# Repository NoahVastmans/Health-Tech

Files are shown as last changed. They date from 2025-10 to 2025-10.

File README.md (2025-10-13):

# 🎾 SmartServe Ball — Intelligent Motion Guidance and Apex Detection

## 📘 Project Overview

The **SmartServe Ball** project combines embedded sensing, wireless communication, and data analysis to accurately detect and predict the **apex** of a tennis ball’s trajectory during a throw or serve.

Using a **Seeed XIAO BLE Sense** microcontroller with a **6-axis IMU (LSM6DS3)**, the system identifies:
- The **start of free fall**
- The **apex (highest point)** of the throw
- The **catch or impact moment**
- And transmits timing data via **Bluetooth Low Energy (BLE)**

The goal is to provide **real-time motion insight** for sports technology, validation through **video tracking**, and a foundation for further embedded motion analytics.

---

## 📁 Repository Structure

### 🧠 `Arduino Scripts/`
Contains all embedded code for the SmartServe Ball, including:
- **Apex detection**, **free-fall**, and **BLE telemetry algorithms**
- Modified **`LSM6DS3.cpp`** file required for stable IMU communication  
  *(instructions are detailed in the script-specific README inside this folder)*

Each Arduino script is fully documented in-code.

---

### ⚡ `Electrical Circuit/`
Includes the electrical design and assembly details:
- **KiCad project files** for the wiring and sensor connections  
- **Photos** of the final sensor assembly

> 💡 The PCB was **not fully designed** in CAD — instead, an **adaptable PCB prototyping board** was used.  
> This allowed greater flexibility for multi-layer connections and double-sided component placement.

---

### 🧱 `Prototype Sensor Case/`
3D design files for the **protective casing** used to house the electronics inside a **tennis ball**.  
The case ensures durability while maintaining balance and minimal aerodynamic impact.

---

### 🎥 `Video Tracking/`
Contains:
- The **validation videos** used to visually confirm the apex timing  
- **Video tracking scripts** for extracting apex frames and timestamps  
- A **comparison file** matching BLE-detected and predicted times to the visual apex times

This folder provides the link between **experimental results** and **sensor-based detection accuracy**.

---

### 📹 `Explanation Video/`
A short **demonstration video** summarizing the SmartServe Ball project — explaining the concept and system design in a clear visual format.

---

### 🖥️ `Presentation/`
Contains the **final project presentation slides**, summarizing:
- Motivation and goals  
- Technical design (hardware + software)  
- Validation results and future improvements  

---

### 📄 `Scientific Paper/`
Includes a **concise research-style paper** presenting:
- The experimental setup  
- Measured results  
- Comparison between prediction and detection  
- Relevant literature and references  

---

### 🕰️ `Legacy/`
Contains earlier versions of scripts and design assets intended for future development.  
A separate README inside this folder explains each file’s purpose and how to build upon it.

---

## 🧩 Summary

| Component | Description |
|---|---|
| **Embedded Code** | Apex detection, prediction, BLE telemetry |
| **Electronics** | IMU wiring and modular circuit design |
| **Mechanical Design** | 3D CAD for protective case |
| **Validation** | Video-based apex verification |
| **Demonstration** | Project explanation video |
| **Documentation** | Presentation slides and scientific paper |
| **Legacy Work** | Early-stage materials for continuation |

---

## 🔬 Purpose

The SmartServe Ball demonstrates how **low-power embedded sensing** and **motion algorithms** can yield **accurate trajectory analytics** for sports applications.  
It combines open hardware, transparent validation, and modular design to serve as a **research and development platform** for motion-based performance tracking.

---

## 🧾 License

This repository is open for **educational and research use**.  
Please credit the **SmartServe Ball Project** when reusing or modifying any material.

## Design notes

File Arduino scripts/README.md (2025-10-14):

# 🎾 SmartServe Ball — Apex Detection, Apex Estimation & BLE Telemetry

## 📖 Overview

**SmartServe Ball** is an embedded system that detects and measures the motion of a thrown object using a **6-axis IMU (LSM6DS3)** and **Bluetooth Low Energy (BLE)**.

It automatically detects:
- **Free fall start** and **catch impact**
- The **apex (highest point)** of flight
- **Predicted vs. actual apex times**
- And emits a **buzzer signal** for video synchronization or real-time feedback.

Flight metrics are transmitted via BLE to a connected device (e.g., smartphone, PC, or logging app).

---

## 🧭 Setup Prerequisites

Before you begin, make sure your development environment is correctly configured for the **Seeed XIAO BLE Sense**.

1. 📘 **Read the official Seeed Studio setup guide:**  
   👉 [https://wiki.seeedstudio.com/XIAO_BLE/](https://wiki.seeedstudio.com/XIAO_BLE/)  
   This page explains how to properly set up the board, drivers, and Arduino environment.

2. ⚙️ **Install the correct board package:**  
   In the Arduino IDE, go to  
   `Tools → Board → Board Manager`  
   and install:  
   **“Seeed nRF52 mbed-enabled Boards”**  
   **Do not install the non-mbed version**, as it may cause upload and sensor initialization issues.

Once the board package is installed, select:  
`Tools → Board → Seeed XIAO BLE Sense`

---

## ⚙️ System Features

| Feature | Description |
|---|---|
| **Free-fall detection** | Detects when acceleration drops below ~0.1 g |
| **Apex detection** | Zero-crossing of filtered vertical velocity |
| **Apex prediction** | Calculates time to apex based on release velocity |
| **Catch detection** | Detects when acceleration rises after flight |
| **BLE transmission** | Sends flight metrics as a comma-separated string |
| **Buzzer feedback** | Beeps at apex for video synchronization |
| **Continuous mode** | Supports multiple throws in sequence |

---

## 🧩 Hardware Requirements

- **Seeed XIAO BLE Sense** or compatible BLE-enabled Arduino board  
- **LSM6DS3 IMU** (integrated or connected via I²C)
- **Buzzer** connected to **pin 5**
- Optional: mobile app or BLE logger to receive flight data

---

## 🔧 Software Requirements

- **Arduino IDE 2.x**  
- **Libraries:**
  - `LSM6DS3` (Seeed version)
  - `ArduinoBLE`
  - `Wire`

---

## ⚠️ Important — LSM6DS3.cpp Modification

Before running this code, you **must replace** the `LSM6DS3.cpp` file in your installed library folder with the **modified version** included in this project.

This modified file ensures **stable and faster sensor reads** compatible with the SmartServe Ball’s timing requirements.

### 🔹 Steps to Replace the File:

1. Locate your LSM6DS3 library folder:
   - **Windows:**  
     `Documents/Arduino/libraries/Seeed_Arduino_LSM6DS3/`
   - **macOS/Linux:**  
     `~/Documents/Arduino/libraries/Seeed_Arduino_LSM6DS3/`

2. Find and replace the file:
   - Replace the original `LSM6DS3.cpp` with the version found in this SmartServe Ball project folder.

3. Restart the Arduino IDE.

---

## 🧠 Algorithm Summary

### 1. **Sampling**
- The IMU is sampled at **52 Hz** (`fs = 52.0`).
- Each cycle reads acceleration and computes its norm.

### 2. **Filtering**
- **Low-pass filter** smooths acceleration (`fc_acc = 5 Hz`).
- **High-pass filter** integrates to get drift-free velocity (`fc_vel = 50 Hz`).

### 3. **Free-Fall Detection**
- Triggered when acceleration norm < `FREEFALL_THRESH` (≈ –7 m/s²) for at least `FREEFALL_MIN` s.

### 4. **Apex Prediction**
- Using initial velocity (`v₀`), predicts the time to apex:  
  `t_pred = v₀ / g`

### 5. **Apex Detection**
- Detected when filtered velocity crosses zero (positive → negative).
- A buzzer beep is scheduled with a delay compensation of `filter_delay` s.

### 6. **Catch Detection**
- Ends flight when acceleration norm > `CATCH_THRESH` (≈ 1 m/s²).

### 7. **BLE Transmission**
- Sends a string formatted as:  
  `t_pred_apex, apex_since_freefall, freefall_duration`

Example: `0.735, 0.740, 1.488`

---

## 📡 BLE Data Format

| Field | Description | Units |
|---|---|---|
| `t_pred_apex` | Predicted time from release to apex | s |
| `apex_since_freefall` | Actual measured apex time (since free-fall start) | s |
| `freefall_duration` | Total flight time | s |

BLE UUIDs:
- **Service:** `180A`  
- **Characteristic:** `2A57`

---

## 🔔 Buzzer Behavior

| Event | Action |
|---|---|
| Free fall start | Short tone (500 Hz, 100 ms) |
| Apex | 1 kHz tone, delayed by `filter_delay` |
| Catch | No tone; BLE data sent |

---

## ⚙️ Tuning Parameters

| Parameter | Description | Default |
|---|---|---|
| `fs` | Sampling frequency | 52 Hz |
| `fc_acc` | Low-pass cutoff for acceleration | 5 Hz |
| `fc_vel` | High-pass cutoff for velocity | 50 Hz |
| `FREEFALL_THRESH` | Acceleration threshold (≈ 0.1 g) | –7.0 m/s² |
| `FREEFALL_MIN` | Minimum time below threshold | 0.04 s |
| `CATCH_THRESH` | Catch detection threshold | 1.0 m/s² |
| `filter_delay` | Apex delay compensation | 0.12 s |
| `buzzerDuration` | Tone duration | 500 ms |

---

## 📈 Example BLE Output

```
0.733, 0.751, 1.486
0.812, 0.798, 1.612
0.705, 0.739, 1.423
```

Each line corresponds to one complete throw:
1. Predicted apex time  
2. Detected apex time since free-fall start  
3. Flight duration (end – start)

---

## 🚀 Usage Steps

1. Replace the **LSM6DS3.cpp** file as described above.  
2. Open the `Apex_detection_and_prediction.ino` sketch in Arduino IDE.  
3. Select your board (e.g., Seeed XIAO BLE Sense) and COM port.  
4. Upload the sketch.  
5. Open a BLE terminal or app (e.g., **nRF Connect**, **Serial Bluetooth Terminal**).  
6. Start throwing the ball — observe BLE data and buzzer signals.

---

## 🧰 Future Extensions

- Include **gyro-based orientation** for 3D trajectory tracking.  
- Add **drag correction** to apex prediction.  
- Store data on the **internal flash memory** of the Seeed board, allowing for **delayed Bluetooth transmission** — removing the need for a constant connection to retrieve data.
---

## 📄 License

This project is open for educational and research use.  
Please credit the **Smart Ball Project** when redistributing or modifying.

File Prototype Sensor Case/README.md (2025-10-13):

# 🧱 Prototype Sensor Case
3D design files for the protective casing used to house the electronics inside a tennis ball.
The case ensures durability while maintaining balance.

## 📘 Overview

This folder contains all **cad design resources** for the SmartServe Ball project.  
The 3D printed case is design to work with the first version of the SmartServe Ball as described in **electrical design resources**.

---

## 🧩 Contents

| Item | Description |
|---|---|
| `sensor case_prototype.step` | sensor case concept for SmartServe Ball in .step format |
| `sensor case_prototype.sldprt` | sensor case concept for SmartServe Ball in .sldprt format |
| `assembly` | Image of the final sensor assembly for a tennis ball integration in a "Exploded" view |

---

## 🧠 Design Notes

- The sensor case serves purpose as a **proof of concept** for rapid prototyping.
- It is designed to be manufactured in a **3D printing machine** under the material of **Polyurethane (PTU)**.
  -  Flexibility and Elasticity
  -  Tensile Strength
  -  Impact Resistance
  -  Tear Resistance
- Tailormade designed to the specific dimensions of the SmartServe Ball.
- Design pivots from the manufacturing process of a tennis ball.
- The **sensor case itself was not tested** by any FEA system or physical examination.

---

## 🔌 Implementation Overview

The assembly image illustrates: 
- **Tennis Ball Outer Felt layer** 6cm diameter  
- **Tennis Ball Inner Rubber Core** 3mm thick
- **Sensor case prototype**
- **SmartServe Ball sensor system**
    
---

## 🧰 Tools

- **Any CAD design software** (for viewing and editing files)  
- **SolidWorks** (original CAD designed software use)

Consideration when opening the part:
1. Model uses external reference of the components of the SmartServe Ball.  
2. Therefore, to use in other systems.
  a. External references may need to be broken.
  b. Adjust contour sketches to match the components' dimensions.  

---

## 🧾 License

These files are shared for **educational and research purposes** under the SmartServe Ball project.  
Please credit the **SmartServe Ball Team** when reusing or adapting the schematic or library components.

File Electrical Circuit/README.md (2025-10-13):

# ⚡ SmartServe Ball — Electrical Circuit

## 📘 Overview

This folder contains all **electrical design resources** for the SmartServe Ball project.  
The system connects a **Seeed XIAO BLE Sense** microcontroller to a **buzzer** and other peripheral components.

---

## 🧩 Contents

| Item | Description |
|---|---|
| `SmartServeBall.kicad_sch` | Main circuit schematic showing all connections between the XIAO BLE Sense, IMU, and buzzer |
| `SmartServeBall.kicad_pro` | KiCad project configuration file |
| `Seeeduino XIAO KICAD/` | KiCad symbol and footprint files for Seeed components (used in the schematic) |
| `Assembly Photos/` | Images of the final sensor assembly and adaptable PCB setup |

---

## 🧠 Design Notes

- Only the **schematic** was designed digitally in KiCad.  
- The **PCB itself was not routed** in KiCad or fabricated.

Instead, an **adaptable prototyping PCB** was used for greater flexibility:
- Components were mounted on **both sides** of the board.  
- Components were mounted on top of each other to save space.  
- This approach allowed **rapid iteration** and **easy modification** during testing and validation.

---

## 🔌 Connection Overview

The schematic illustrates: 
- **Power lines** (`3.3V` and `GND`) shared between all components  
- **Digital output pin (D5)** used to drive the **buzzer** for apex and event feedback

---

## 🧰 Tools

- **KiCad 7.x or later** (for viewing and editing schematic files)  
- **Seeeduino XIAO KICAD Library** (included in this folder)

To open the schematic correctly:
1. Ensure the `Seeeduino XIAO KICAD/` folder is in the same directory as the `.kicad_pro` file.  
2. Open `SmartServeBall.kicad_pro` in KiCad.  
3. Verify that component symbols and footprints load without errors.

---

## 🧱 Assembly Process

The assembly was performed in several structured steps to create a compact and robust sensor module:

1. **Top Layer Soldering:**  
   The first layer of components was soldered on the **upper side** of the adaptable PCB.  
   This included the **buzzer**, **resistor**, and **pin extensions** for the Seeed XIAO BLE Sense.

2. **Power Wiring:**  
   Next, the **power supply wires** were soldered to the corresponding **3.3V** and **GND** pins, ensuring solid electrical contact and mechanical stability.

3. **Base Layer Protection:**  
   After soldering the lower connections, a **thin layer of hot glue** was applied to the **bottom side** of the PCB to insulate and protect the solder joints.

4. **Battery Holder Placement:**  
   The **battery holder** was then positioned directly on top of the glued surface, forming the **second hardware layer** of the design.

5. **Final Power Connection:**  
   Finally, the **power wires** were soldered to the **battery holder terminals**, completing the electrical circuit and enabling portable operation.

This stacked-layer assembly provided an **efficient use of space** and **robust wiring**, allowing the electronics to fit neatly inside the SmartServe Ball’s protective enclosure.

---

## 📷 Assembly

The `Assembly_Photos/` folder shows:
- The **adaptable PCB layout**  
- The **component placement** on both board sides  

These images serve as a **reference for replication or redesign**.

---

## 🧾 License

These files are shared for **educational and research purposes** under the SmartServe Ball project.  
Please credit the **SmartServe Ball Team** when reusing or adapting the schematic or library components.

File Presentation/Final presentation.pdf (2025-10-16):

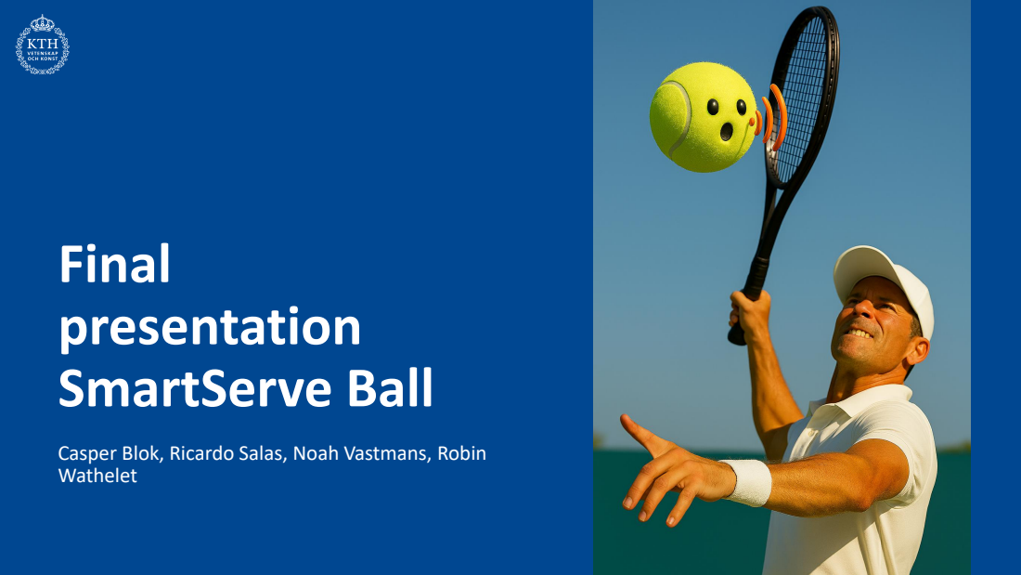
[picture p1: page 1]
Final presentation SmartServe Ball

Casper Blok, Ricardo Salas, Noah Vastmans, Robin
Wathelet

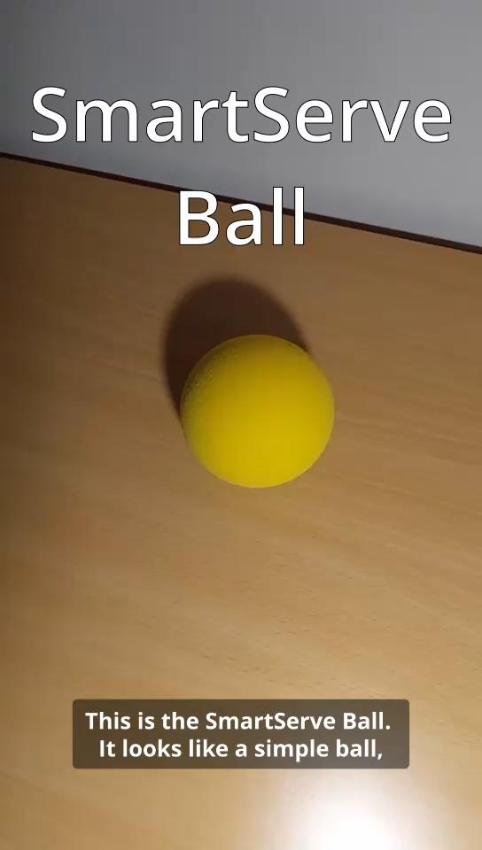
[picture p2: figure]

# Video

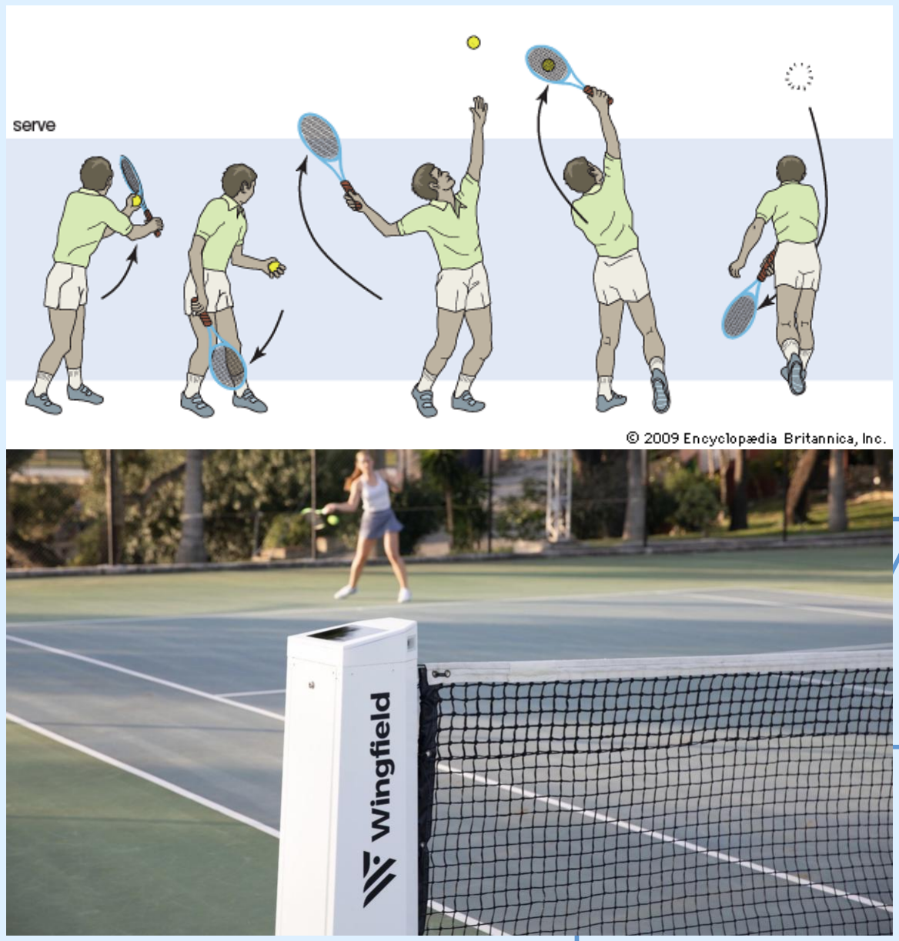
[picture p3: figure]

# Problem Statement

- Difficult evaluation of tennis serve timing
- Alternative solutions:
- Coach → unreliable
- Video analysis → expensive setup

# Technical design

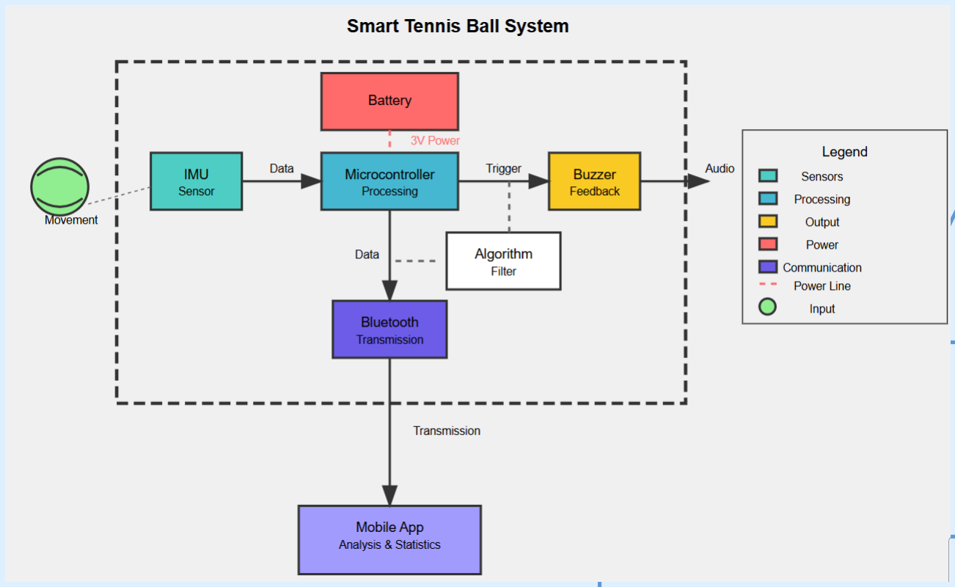
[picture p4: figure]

- Seeed Studio XIAO nRF52840 Sense board
- IMU
- Microcontroller
- Bluetooth module
- Integrated electrical circuit with buzzer and coin battery
- Training foam ball

# Technical design

- Velocity reconstruction from acceleration
- Freefall detection: flight time
- Apex detection → trigger acoustic feedback

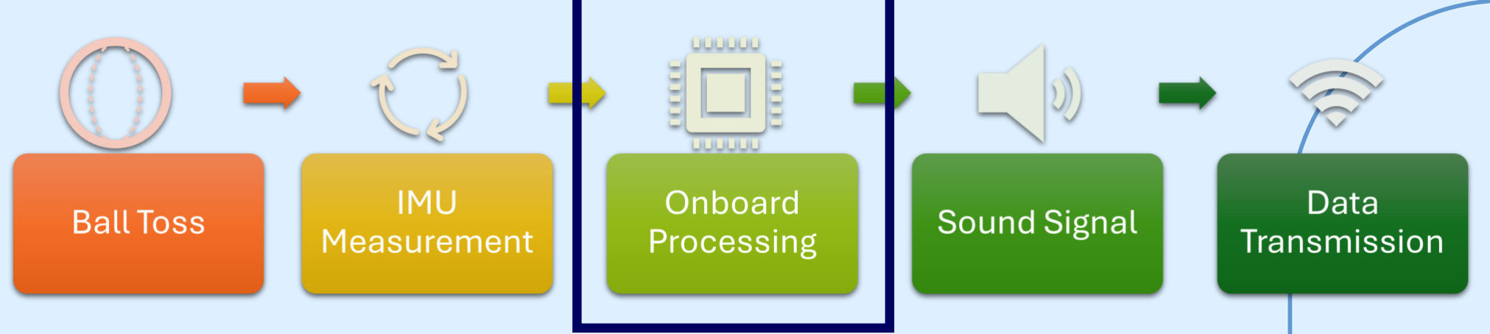
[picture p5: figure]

# User Interaction

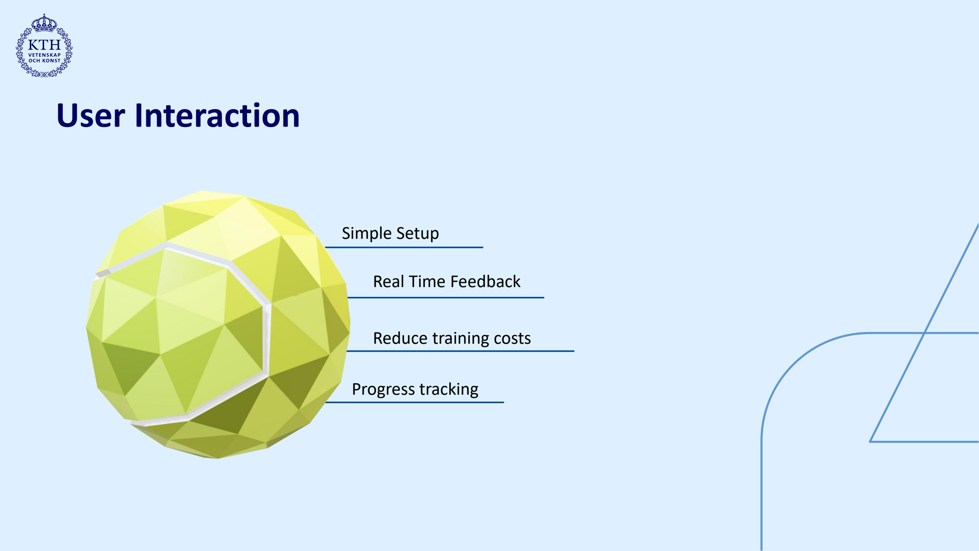
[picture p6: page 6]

Simple Setup

Real Time Feedback

Reduce training costs

Progress tracking

# Results

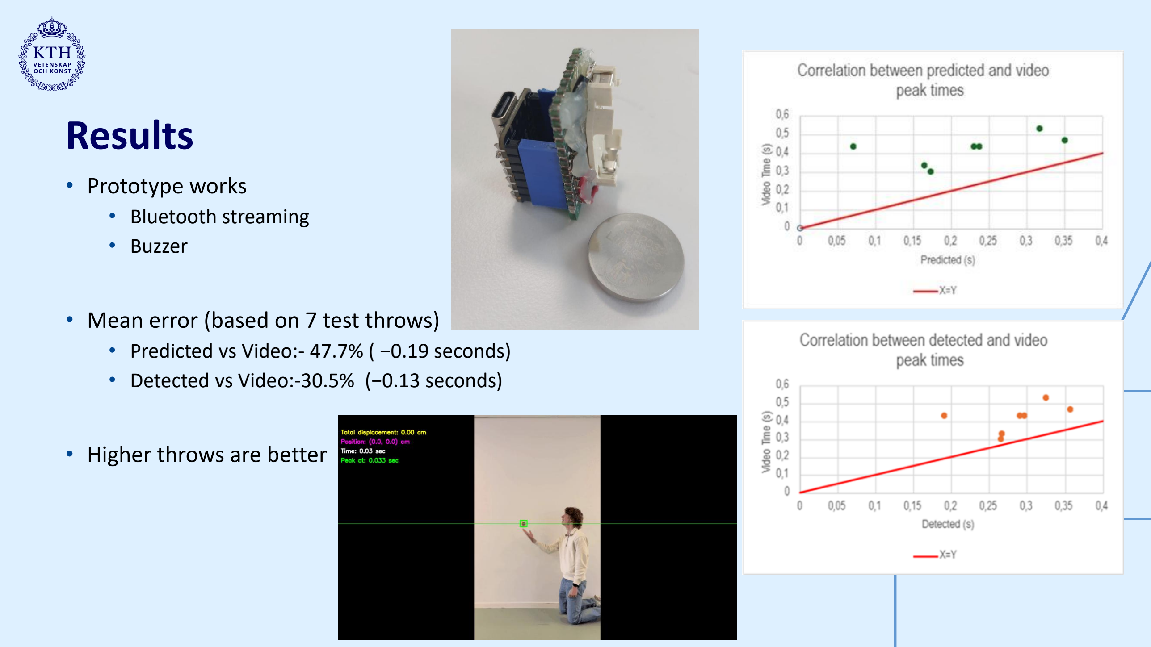
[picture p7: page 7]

- Prototype works
- Bluetooth streaming
- Buzzer
- Mean error (based on 7 test throws)
- Predicted vs Video:- 47.7% ( −0.19 seconds)
- Detected vs Video:-30.5% (−0.13 seconds)
- Higher throws are better

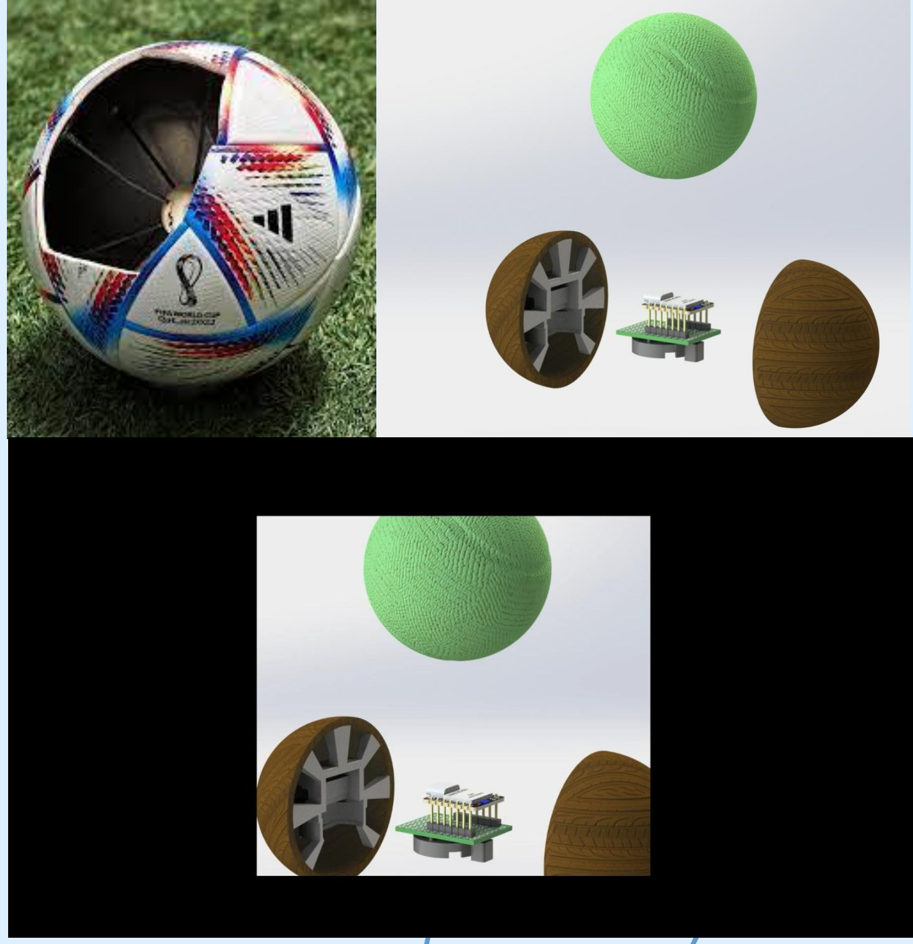
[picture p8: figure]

# What's next

- Integration into a real tennis ball
- Provide sufficient integrity
- Center of rotation
- Affect minimal initial properties
- Weight
- Balance
- Elasticity
- Improve accuracy
- Both detection and video validation
- Onboard data storage → delayed transmission
- App design for progress tracking

# Other Uses

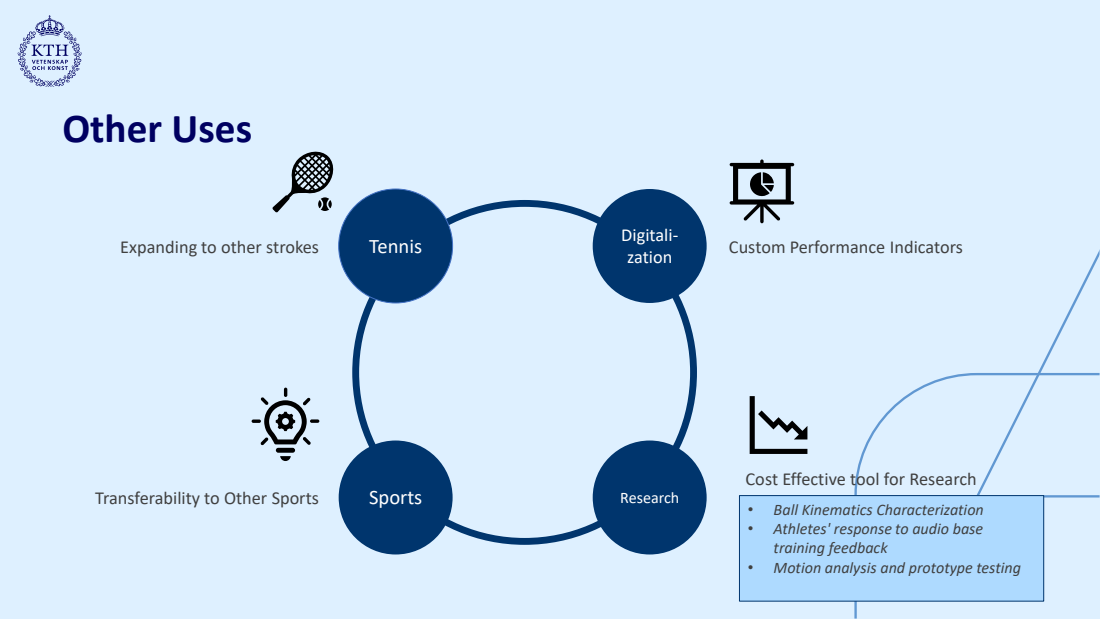
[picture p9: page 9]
Tennis; Digitali-; zation; Sports; Research

Expanding to other strokes

Custom Performance Indicators

Cost Effective tool for Research

Transferability to Other Sports

• Ball Kinematics Characterization
• Athletes' response to audio base
training feedback
• Motion analysis and prototype testing

# Project Methodology

Positive
- Weekly meetings
- Strong communication

Leasons learned
- More communication between members about their work
- Seeking help at an earlier stage when stuck

The group dynamic is centered around an open table discussion.
- Brainstorming
- Collectively discuss ideas
- Parallel work

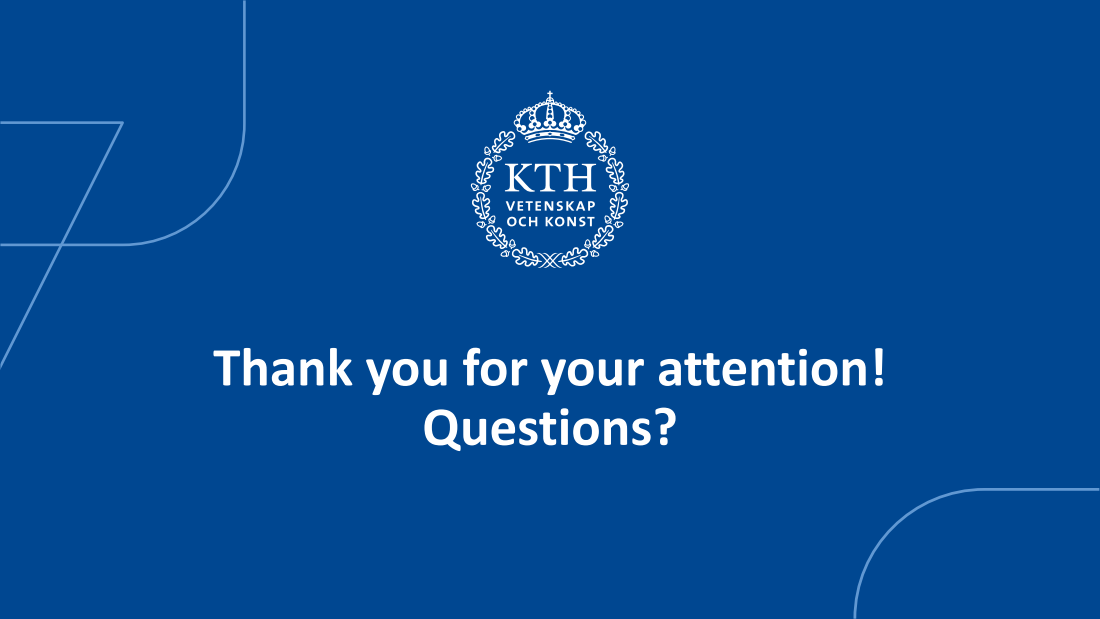
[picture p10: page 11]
Questions?

Thank you for your attention!

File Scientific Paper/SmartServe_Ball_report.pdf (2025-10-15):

CM 2024: Technology and Health, project course | October 15, 2025

## SmartServe: A Sensor-Embedded Tennis Ball for Real-Time Apex Detection and Feedback

Casper Blok, Ricardo Salas, Noah Vastmans, Robin Wathelet

Abstract

This project addresses the challenge of improving tennis serve technique by accurately detecting the apex of the ball toss. A critical aspect of the serve is timing the strike, as mistimed serves reduce performance consistency and are difficult for players to correct without precise feedback. To address this, we developed SmartServe, a prototype ball equipped with a Seeed nRF52840 board and custom firmware designed to detect and record the highest point of the toss. The system provides real-time audio cues to guide the player. The tests showed that SmartServe identified the apex with an average accuracy of −30% in repeated trials, demonstrating robust sensing and reliable data retrieval.

## Introduction

In tennis, one of the key factors that determines the outcome of a match is the ability to serve [1]. The quality of the serve is strongly influenced by the timing between the ball toss and impact [2]. However, amateur players often struggle to consistently recognize and time their swing [3, 4].
Current methods for improving serve timing rely heavily on subjective or indirect approaches. The most common method is coach feedback, which provides expert guidance but depends on the coach’s availability and observational accuracy. More advanced motion tracking systems, such as radar or camera-based sports analytics tools, can provide detailed measurements of ball speed and spin. Still, their high cost and operational complexity make them beyond the reach of most players [5, 6]. These systems have primarily been applied in scientific research contexts, requiring extensive data analysis [3, 4, 7], and are also used in elite tournaments, Hawk-Eye being the most widely adopted system [8]. Recent studies have explored more affordable setups, achieving promising results, but these require post-processing (i.e., AdaBoost algorithms to video track small objects [9]).
These approaches highlight the need for a more direct, in-situ solution capable of measuring toss timing directly on the ball without relying on external equipment. Incorporating sensors into sports equipment provides a practical means to address this challenge, enabling detailed, real-time data collection. Sensorequipped balls have already been applied across multiple sports disciplines. Examples include the Adidas miCoach Smart Ball [10], 94Fifty Smart Sensor Basketball [11], GEN i1 Smart Golf Ball [12], and pitchLogic Ball [13]. For tennis, similar approaches have primarily focused on the racket rather than the ball, with commercially available products such as the Sony Smart Tennis Sensor and Babolat Play racket [14]. More recently, Foot et al. (2025) demonstrated the integration of an IMU sensor into an IPFapproved Vermont 90 mm foam tennis ball, with the system designed to measure accurate ball RPM during groundstrokes [15].
The contributions of this paper focus on a smart tennis ball prototype that integrates a Seeed nRF52840 microcontroller with onboard motion sensors to detect the apex of a serve in real time using acceleration and velocity measurements. The embedded system implements algorithms for free-fall detection, velocity reconstruction, and zero-crossingbased apex identification, while providing acoustic feedback and wireless data transmission for immediate and post-session analysis. Experimental evaluation demonstrated apex detection with an average error of approximately −30% relative to video tracking. These results, combined with the compact and robust hardware design, highlight the potential of inball sensing to deliver immediate, quantitative feedback, offering a practical and accessible tool for tennis training.

## Design

The smart tennis ball prototype was built around the Seeed Studio XIAO nRF52840 Sense board, which integrates a Nordic nRF52840 microcontroller, a sixaxis inertial measurement unit (IMU), and Bluetooth Low Energy (BLE) functionality. The microcontroller provides sufficient computational power for onboard signal processing while maintaining low energy consumption. The integrated IMU enables the measurement of both linear acceleration and angular velocity, which are critical for estimating ball speed and detecting the apex of the toss. The integrated BLE module allows wireless data transfer, enabling recorded measurements to be retrieved after play without a physical connection. To facilitate integration of the electronics, a foam-based training tennis ball was used, providing sufficient volume and flexibility to embed the components while preserving the general shape and handling of a tennis ball. This combination of sensing, processing, and communication in a compact form factor enabled the construction of a functional and durable prototype. An overview of the system design and signal flow is presented in Figure 1.

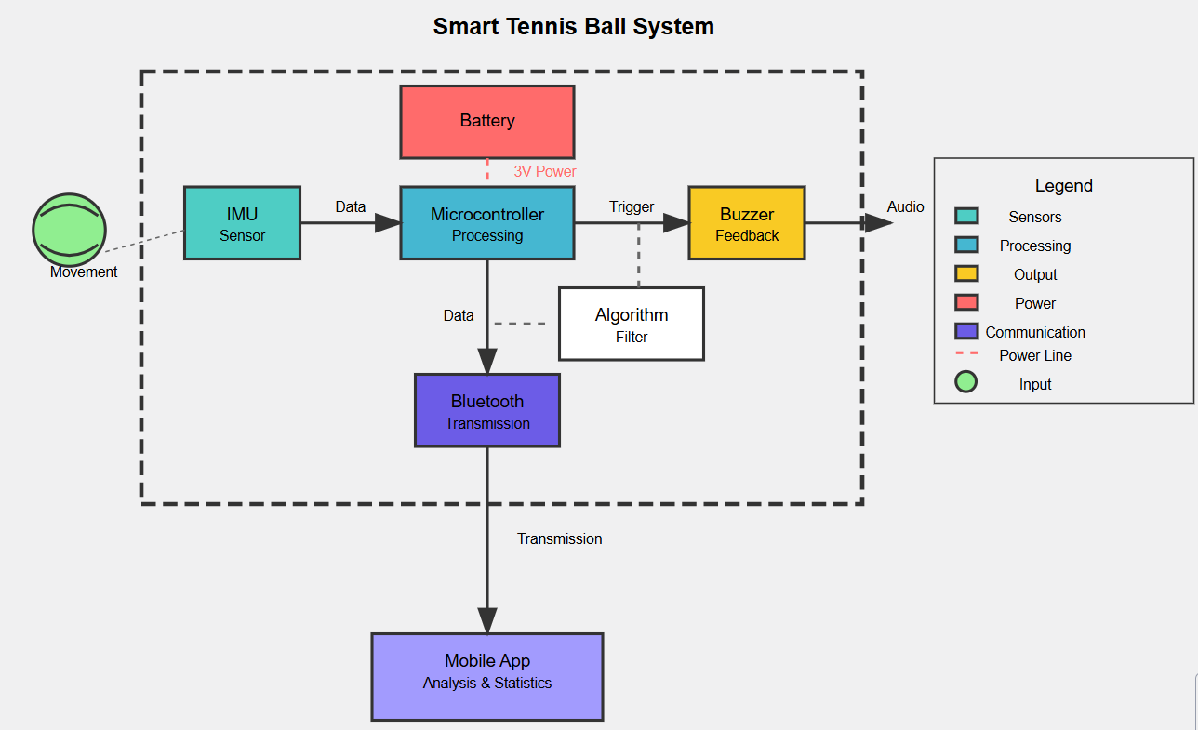
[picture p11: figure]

Figure 1: Schematic design diagram

The control unit was assembled according to the schematic design, combining the Seeed Studio XIAO nRF52840 Sense board, power supply, buzzer, and wiring into a compact and functional prototype. The layout was optimised to ensure reliable operation during testing. This prototype enabled practical validation of the sensing algorithms and the acoustic feedback system, serving as a bridge between the conceptual design and a fully integrated smart tennis ball. An image of the assembled unit is shown in Figure 2.

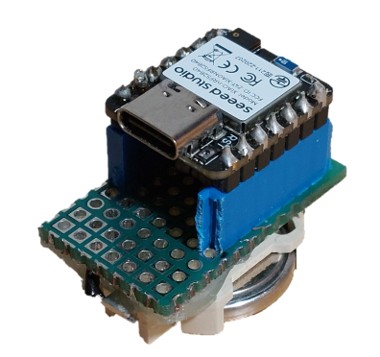
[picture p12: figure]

Figure 2: Sensor assembly

The | Seeed | plat-
form enabled implementation of the developed algorithms in
C++ | for | real-time
apex | detection | and
acoustic feedback using
the Arduino IDE. The
IMU’s inertial data,
obtained from the onboard LSM6DS3 sensor, were sampled at

52Hz. The acceleration norm was computed as

∥a∥ =

q
a

2
x + a

2
y + a

2
z − g | (1)

where ax, ay, and az represent the acceleration components along the three axes, and g denotes gravitational acceleration. The signal was low-pass filtered at 5 Hz to reduce measurement noise, then high-pass filtered at 0.5 Hz to compensate for drift and obtain a stable velocity estimate.
Free-fall initiation was detected when ∥a∥ dropped below −7m/s²
for a minimum duration of 40ms, and
flight termination when it exceeded 1m/s² | . During
the flight phase, the apex was identified by detecting a zero-crossing in the filtered vertical velocity, marking the transition from upward to downward motion. The initial release velocity was further used to predict the expected time to apex, allowing synchronisation of the acoustic feedback generated by the buzzer. All relevant timing and motion data were transmitted via BLE for post-analysis.
For system validation, video tracking was performed using a custom Python-based tool to record and compare actual apex events against those detected by the IMU-based system. This setup allowed quantitative assessment of detection accuracy and latency, providing a reliable framework for subsequent performance evaluation.

## Results

The SmartServe system was fully functional during testing, including the complete electrical circuit, buzzer, and Bluetooth communication with a mobile device. To receive the data, the nRF Connect app was used.
To examine the validity of the system, a series of ball throws (N = 7) were recorded, varying in height between approximately ∼ 50cm and ∼ 150cm. During these trials, synchronized video recordings were captured to establish a ground truth. Using video tracking, the time to apex was determined and subsequently compared with both the predicted and detected apex times calculated by the SmartServe system.
The results of this analysis are presented in Figures 3 and 4. The predicted time to the apex showed a mean error of −47.7% (−0.19s) relative to the videobased reference, while the detected time exhibited a mean error of −30.5% (−0.13s). These findings indicate that both the predicted and detected apex times occurred substantially earlier than the ground truth. The observed errors fall outside the acceptable range for reliable application in training scenarios, suggesting that further refinement of the system is necessary. The approximately linear relationship between the observed errors and the time to apex implies that a mathematical correction factor or calibration model could potentially improve the accuracy of both prediction and detection.

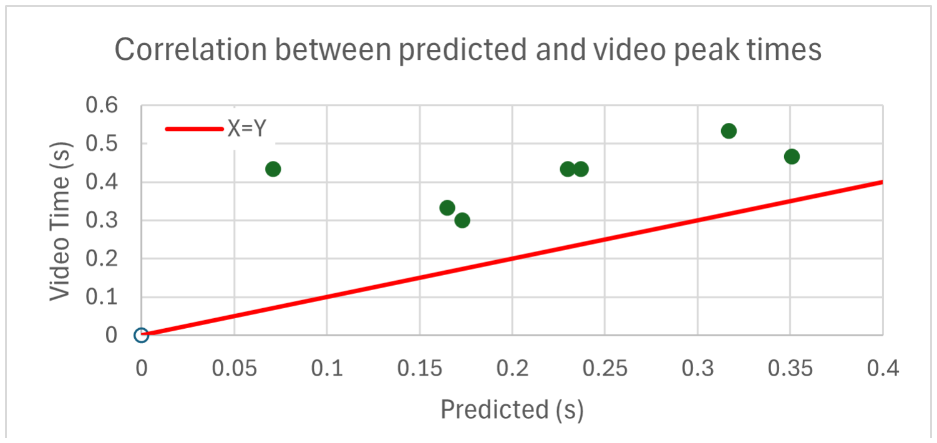
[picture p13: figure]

Figure 3: Results of video tracking analysis (Video vs predicted)

During testing, it was observed that excessive ball rotation caused failures in the free-fall detection, likely leading to the inaccurate apex estimation. This issue highlights a key limitation of the current design, as the algorithm assumes a relatively vertical throw for the calculated acceleration to accurately represent the overall motion. When the throw deviates from this vertical trajectory, the correlation between measured and actual acceleration decreases, resulting in reduced reliability. To address this, a rotationcorrection algorithm would be required to properly extract the vertical velocity component and improve the robustness of apex detection under realistic serve conditions.

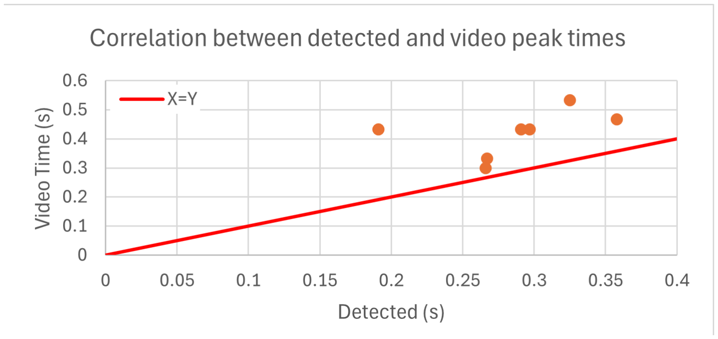
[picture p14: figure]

Figure 4: Results of video tracking analysis (Video vs detected)

Two key insights were derived from the analysis. First, the reliability of the SmartServe system appeared to improve with higher ball throws, corresponding to longer times to apex. This trend suggests that the system performs more consistently under conditions resembling actual tennis serves, which is promising for its intended application. Second, a similar improvement was observed when comparing the predicted apex to the detected apex, indicating that the prediction algorithm is also more reliable in servelike trajectories. These findings collectively suggest that while the current implementation requires further refinement, the system shows potential for accurate real-time feedback in realistic tennis-serving conditions.

## Conclusion

The evaluation of the SmartServe prototype demonstrates the feasibility of detecting the apex of a tennis ball toss using onboard sensing and real-time processing. The system successfully integrates motion sensing, wireless communication, and acoustic feedback into a compact platform, and initial tests confirm that apex detection is achievable with reasonable temporal precision. Although the current implementation exhibits timing errors that exceed the acceptable range for training applications, the results indicate that performance improves under conditions resembling real tennis serves, suggesting strong potential for further development.
Future work will focus on improving the accuracy and reliability of apex detection through refined algorithms and calibration procedures. The next design iteration will integrate the electronics into a regulation tennis ball, requiring a rechargeable battery, a redesigned PCB optimized for mass production, and robust mechanical embedding to keep the components centered without altering the ball’s physical properties. Existing prototype CAD files will serve as the foundation for this development. Data storage on the internal flash memory of the Seeed board will be added to enable delayed Bluetooth transmission, removing the need for a constant connection to retrieve data. Finally, a companion mobile application will be developed for progress tracking and customizable acoustic feedback, allowing users to adjust tone timing based on predictive rather than purely detected events.

## Appendix

All related resources — including the embedded code, electrical schematics, validation videos, 3D CAD files, and documentation — are available in the SmartServe Ball GitHub repository: https://github.com/NoahVastmans/SmartServeBall (https://github.com/NoahVastmans/SmartServeBall)

## References

[1] Machar Reid, Darren McMurtrie, and Miguel Crespo. “The relationship between match statistics and top 100 ranking in professional men’s tennis”. In: International Journal of Performance Analysis in Sport 10.2 (2010), pp. 131–138.
[2] Jan Carboch and Denisa Hrychová. “Kinematic Analysis of the Serve Toss and its Impact on Serve Outcome in Competitive and Recreational Tennis Players: A Case Study”. In: International Journal of Physical Education, Fitness and Sports 14.1 (2025), pp. 45–51.
[3] A. P. Xavier et al. “Ball position during the tennis serve toss performed by junior athletes: comparison between the first and second service”. In: Journal of Physical Education and Sport (JPES) 17.1 (2017).
[4] Jan Vacek et al. “A systematic review of spatial differences of the ball impact within the serve type at professional and junior tennis players”. In: Applied Sciences 13.6 (2023), p. 3586.
[5] F. Tubez et al. “Which tool for a tennis serve evaluation? A review”. In: International Journal of Performance Analysis in Sport 17.6 (2017), pp. 1007–1033. doi: 10.1080/24748668.2017.1419407. (https://doi.org/10.1080/24748668.2017.1419407)
[6] Yuanzhou Chen et al. “Monocular Visual Analysis for Electronic Line Calling of Tennis Games”. In: International Conference on Image and Graphics. Springer. 2021, pp. 528–538.
[7] Julien Jacquier-Bret and Philippe Gorce. “Kinematics of the tennis serve using an optoelectronic motion capture system: are there correlations between joint angles and racket velocity?” In: Sensors 24.11 (2024),
p. 3292.
[8] Hawk-Eye | A global leader in the live sports arena. Oct. 2025. url: https://www.hawkeyeinnovations.com/.
[9] Ayad A Namah, Nabeel M Mirza, and Ali A Al-Zuky. “Target detection in video images using HOG-based cascade classifier”. In: Revue d’Intelligence Artificielle 36.5 (2022), p. 709.
[10] adidas - miCoach Smart Ball. url: https : / / www . unisportstore . se / fotbollsutrustning / adidas -micoach-smart-ball/135726/. (https://www.unisportstore.se/fotbollsutrustning/adidas-micoach-smart-ball/135726/)
[11] Test 94Fifty :: Test 94Fifty. url: https://test-94fifty.myshopify.com/.
[12] GEN i1. url: https://coachlabs.com/collections/geni1.
[13] PitchLogic by F5 Sports. url: https://pitchlogic.com/baseball.
[14] Team Scotland. Smart Tennis Sensors — IN OR OUT? Apr. 2021. url: https://teamscotland.medium.com/smart-tennis-sensors-in-or-out-be110259f028. (https://teamscotland.medium.com/smart-tennis-sensors-in-or-out-be110259f028)
[15] Yu Kit Foo, Xi Li, and Rami Ghannam. “Enhancing tennis practice: sensor fusion and pose estimation with a smart tennis ball”. In: Sensors 24.16 (2024), p. 5306.

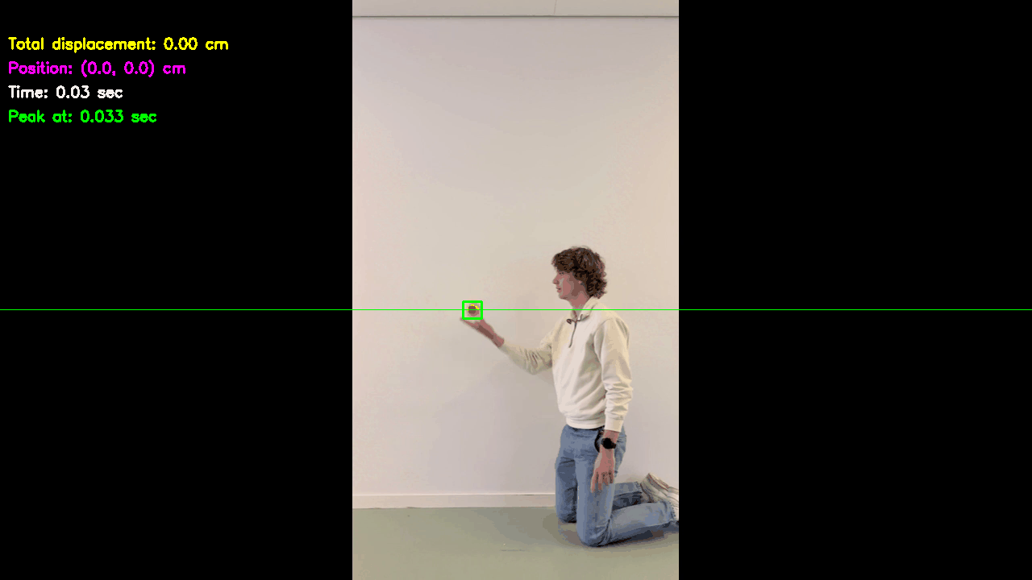
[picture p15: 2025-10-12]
Video Tracking/Output gifs/IMG_5483_1047AM_Cut_tracked.gif

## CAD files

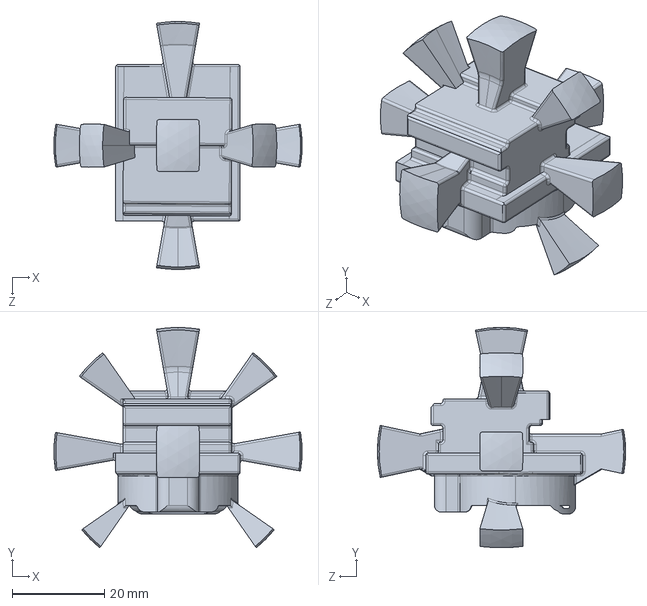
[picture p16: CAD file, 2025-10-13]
Prototype Sensor Case/sensor case_prototype.STEP
53.8 x 47.8 x 53.8 mm

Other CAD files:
Prototype Sensor Case/sensor case_prototype.SLDPRT

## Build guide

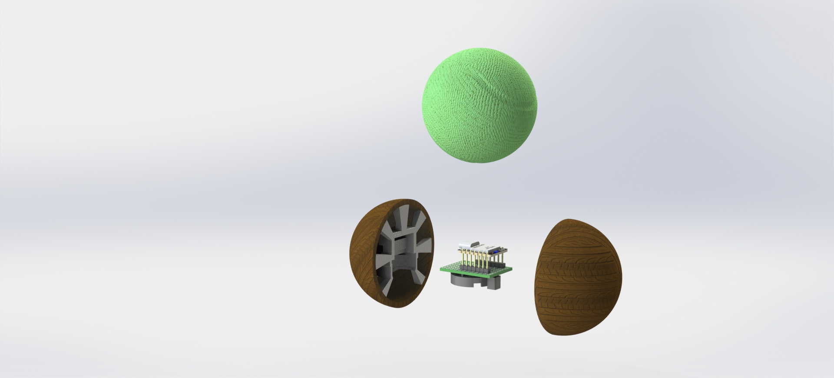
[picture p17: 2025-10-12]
Prototype Sensor Case/assembly.JPG

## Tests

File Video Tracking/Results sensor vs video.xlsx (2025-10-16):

Video | predicted | detected | flight | Video time (Time to peak from first frame) | Difference predict vs video | Difference detect vs video | Difference predict vs detect | Average % difference video & detected | Average % difference video & predicted
81 | 0.173 | 0.266 | 0.701 | 0.3 | 0.58 | 0.89 | 0.6503759398 | 69.48 | 52.30
83 | 0.165 | 0.267 | 0.65 | 0.333 | 0.50 | 0.80 | 0.6179775281
84 | 0.237 | 0.297 | 0.81 | 0.433 | 0.55 | 0.69 | 0.797979798 | Mean Error (Predicted vs Video): −0.1983 seconds | Mean Error % Predicted vs Video: −47.7 %
85 | 0.23 | 0.291 | 0.837 | 0.433 | 0.53 | 0.67 | 0.7903780069 | Mean Error (Detected vs Video): −0.1339 seconds | Mean Error % Detected vs Video: −30.5 %
86 | 0.317 | 0.325 | 1.083 | 0.533 | 0.59 | 0.61 | 0.9753846154
87 | 0.071 | 0.191 | 0.823 | 0.433 | 0.16 | 0.44 | 0.3717277487
88 | 0.351 | 0.358 | 1.166 | 0.467 | 0.75 | 0.77 | 0.9804469274

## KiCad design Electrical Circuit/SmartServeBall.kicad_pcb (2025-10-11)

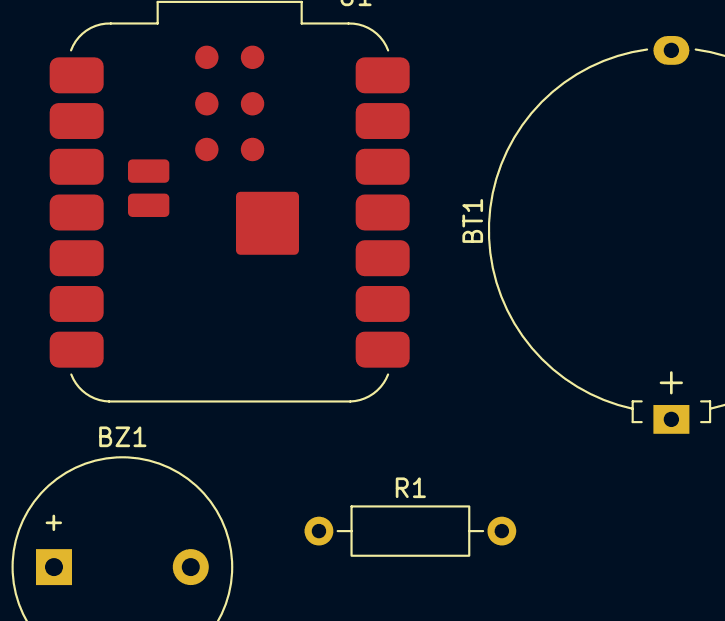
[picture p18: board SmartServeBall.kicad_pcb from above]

Board: 2 copper layers, 4 parts (0 on the bottom side), 4 nets, no tracks yet.

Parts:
BT1: Battery_Cell; Battery_Panasonic_CR2032-HFN_Horizontal_CircularHoles
BZ1: Buzzer; Buzzer_12x9.5RM7.6
R1: 33 Ohm; R_Axial_DIN0207_L6.3mm_D2.5mm_P10.16mm_Horizontal
U1: SeeeduinoXIAO; MCU_Seeed_ESP32C3

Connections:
GND: BT1.2 (-), R1.2, U1.13 (GND)
unnamed: BT1.1 (+), U1.12 (3V3)
unnamed: BZ1.1 (+), U1.5 (PA8_A4_D4_SDA)
unnamed: BZ1.2 (-), R1.1

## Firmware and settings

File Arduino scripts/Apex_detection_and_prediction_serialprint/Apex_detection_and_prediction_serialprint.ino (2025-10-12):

#include <Wire.h>
#include <LSM6DS3.h>

//
// ============================================================
//  SmartServe Ball: Apex Detection, Apex Estimation & BLE Output
// ============================================================
//  Features:
//   • Detects free fall and catch events from accelerometer data
//   • Estimates flight apex using filtered velocity zero-crossing
//   • Predicts apex time based on initial velocity
//   • Provides audible buzzer feedback (sync with video)
//   • Transmits timing data via BLE for remote logging
//
//  Hardware:
//   • IMU: LSM6DS3 (I²C address 0x6A)
//   • BLE: ArduinoBLE library (e.g., XIAO BLE)
//   • Buzzer on pin 5
//
// ============================================================
//


// ==== IMU ====
LSM6DS3 imu(I2C_MODE, 0x6A);

// ==== Constants ====
const int buzzerPin = 5;
const float g = 9.81;                          // Gravity constant (m/s²)
const float fs = 52.0;                         // Sampling frequency (Hz)
const float dt = 1.0 / fs;                     // Sampling period (s)

// ------------------------------------------------------------
// FILTER CONFIGURATION
// ------------------------------------------------------------

// Low-pass filter for acceleration (removes high-frequency noise)
const float fc_acc = 5.0;                      // Cutoff frequency (Hz)
float alpha_acc;                               // Filter coefficient
float acc_filt_prev = 0;                       // Previous filtered acceleration
float acc_norm_prev = 0;                       // Previous raw norm

// High-pass filter for velocity (removes drift)
const float fc_vel = 50.0;                     // Cutoff frequency (Hz)
float alpha_vel;
float velo_filt_prev = 0;
float velo_prev = 0;

// ------------------------------------------------------------
// APEX DETECTION
// ------------------------------------------------------------
float last_apex_time = -1000.0;
const float min_velocity = 0.1;                // Threshold to avoid noise-triggered apex (m/s)
const float min_dt = 1.0;                      // Minimum time between apex detections (s)
float velocity = 0;
float velocity_filt = 0;

const float filter_delay = 0.12;               // Compensation delay from filtering (s)

// Buzzer control
bool buzzerActive = false;
unsigned long buzzerStartTime = 0;
const unsigned long buzzerDuration = 500;      // Duration of beep (ms)
bool buzzerStarted = false;

// ------------------------------------------------------------
// FREE FALL DETECTION
// ------------------------------------------------------------
const float FREEFALL_THRESH = -7.0;            // Acceleration threshold (≈0.1 g)
const float CATCH_THRESH = 1.0;                // Threshold indicating catch or impact
const unsigned long FREEFALL_MIN = 0.040;      // Must remain below threshold this long (s)

bool inFreeFall = false;                       // Indicates active flight phase
float freeFallStart = 0.0;
float freeFallEnd = 0.0;
float apex_since_freefall = 0.0;

// ------------------------------------------------------------
// APEX PREDICTION
// ------------------------------------------------------------
float v0_release = 0.0;                        // Estimated release velocity (m/s)
float t_pred_apex = 0.0;                       // Predicted time until apex (s)
float t_pred_absolute = 0.0;                   // Absolute predicted apex time (s)


// ============================================================
//                      SETUP
// ============================================================
/*
  Before running this sketch:
  - Replace the LSM6DS3.cpp file in your Arduino library folder
    with the modified file from this project folder.
    This change ensures correct free-fall register behavior.
*/
void setup() {
  Serial.begin(115200);
  while (!Serial) {
    delay(10);  // Wait until Serial is ready
  }

  pinMode(buzzerPin, OUTPUT);
  Wire.begin();

  // Initialize IMU
  if (imu.begin() != 0) {
    Serial.println("IMU initialization failed!");
    while (1);
  } else {
    Serial.println("IMU initialized!");
  }

  // Compute filter coefficients (1st-order approximations)
  alpha_acc = dt / (dt + 1.0 / (2.0 * 3.14159 * fc_acc));
  alpha_vel = 1.0 / (1.0 + 1.0 / (2.0 * 3.14159 * fc_vel * dt));
}


// ============================================================
//                      MAIN LOOP
// ============================================================

void loop() {

  static unsigned long lastMicros = 0;
  unsigned long now = micros();

  // Run loop at fixed sampling frequency
  if (now - lastMicros >= dt * 1e6) {
    lastMicros = now;

    // --- Read raw accelerometer data (m/s²) ---
    float accX = imu.readFloatAccelX() * g;
    float accY = imu.readFloatAccelY() * g;
    float accZ = imu.readFloatAccelZ() * g;

    float current_time = millis() / 1000.0;

    // --- Compute acceleration norm minus gravity ---
    float acc_norm = sqrt(accX * accX + accY * accY + accZ * accZ) - g;

    // --- Apply low-pass filter to acceleration ---
    float acc_filt = alpha_acc * acc_norm + (1 - alpha_acc) * acc_filt_prev;

    // --- Integrate to get high-pass filtered velocity ---
    velocity_filt = alpha_vel * (velo_filt_prev + acc_filt * dt);


    // ----------------------------------------------------
    //               FREE FALL START DETECTION
    // ----------------------------------------------------
    if (!inFreeFall && acc_norm < FREEFALL_THRESH) {
      // Potential start of free fall
      if (freeFallStart == 0) {
        freeFallStart = current_time;

        // Approximate initial velocity at release
        v0_release = velo_filt_prev + acc_norm_prev * dt;

        // Predict apex time (neglecting drag)
        t_pred_apex = v0_release / g;
        t_pred_absolute = current_time + t_pred_apex;

        Serial.print("🪂 Free fall detected! v0=");
        Serial.print(v0_release, 2);
        Serial.print(" m/s → predicted apex in ");
        Serial.print(t_pred_apex, 3);
        Serial.println(" s.");
      }
      // Confirm free fall after remaining below threshold long enough
      else if (current_time - freeFallStart > FREEFALL_MIN) {
        inFreeFall = true;

        // Short tone to mark start of flight (sync signal)
        tone(buzzerPin, 500, 100);
      }
    }

    // ----------------------------------------------------
    //               FREE FALL END DETECTION
    // ----------------------------------------------------
    else if (inFreeFall && acc_norm > CATCH_THRESH) {
      // Impact or catch detected
      inFreeFall = false;
      freeFallEnd = current_time;
      Serial.println("💥 Landing/impact detected — system reset for next throw.");

      // Reset variables for next throw
      freeFallStart = 0;
      v0_release = 0.0;
      t_pred_apex = 0.0;
      t_pred_absolute = 0.0;
    }

    // ----------------------------------------------------
    //               CANCEL FALSE FREE FALL
    // ----------------------------------------------------
    else if (!inFreeFall && acc_filt >= FREEFALL_THRESH) {
      // Threshold not held long enough — discard
      freeFallStart = 0;
      v0_release = 0;
      t_pred_apex = 0.0;
      t_pred_absolute = 0;
    }


    // ----------------------------------------------------
    //               APEX DETECTION (ZERO-CROSSING)
    // ----------------------------------------------------
    if (inFreeFall) {
      // Detect sign change: upward (positive) → downward (negative)
      if ((velo_filt_prev > 0) && (velocity_filt <= 0)) {
        float apex_time = current_time - dt / 2; // Midpoint between samples

        if ((apex_time - last_apex_time > min_dt)) {
          last_apex_time = apex_time;
          apex_since_freefall = apex_time - freeFallStart + filter_delay;
          Serial.print("🎯 Apex detected at t = ");
          Serial.print(apex_since_freefall, 3);
          Serial.println(" s since launching.");

          // Schedule buzzer for apex mark (after filter delay)
          buzzerStartTime = millis() + filter_delay * 1000;
          buzzerActive = true;

          // Compute error between predicted and actual apex
          float error = apex_time - t_pred_absolute;
          Serial.print("⏱ Prediction error: ");
          Serial.print(error * 1000, 1);
          Serial.println(" ms.");
        }
      }
    }


    // ----------------------------------------------------
    //               UPDATE FILTER STATES
    // ----------------------------------------------------
    velo_filt_prev = velocity_filt;
    velo_prev = velocity;
    acc_norm_prev = acc_norm;
    acc_filt_prev = acc_filt;


    // ----------------------------------------------------
    //               BUZZER CONTROL
    // ----------------------------------------------------
    if (buzzerActive) {
      unsigned long now_ms = millis();

      // Start buzzer after scheduled delay
      if (!buzzerStarted && now_ms >= buzzerStartTime) {
        tone(buzzerPin, 1000);  // Beep at 1 kHz
        buzzerStarted = true;
      }

      // Stop buzzer after fixed duration
      if (buzzerStarted && now_ms >= buzzerStartTime + buzzerDuration) {
        noTone(buzzerPin);
        buzzerActive = false;
        buzzerStarted = false;
      }
    }
  }
}

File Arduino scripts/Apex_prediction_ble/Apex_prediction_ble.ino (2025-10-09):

#include <Wire.h>
#include <LSM6DS3.h>
#include <ArduinoBLE.h>

// ==== IMU ====
LSM6DS3 imu(I2C_MODE, 0x6A);

// ==== Bluetooth ====
BLEService imuService("180A");
BLECharacteristic imuDataChar("2A57", BLERead | BLENotify, 32);

// ==== Parameters ====
const int buzzerPin = 5;
const float g = 9.81;
const float fs = 52.0;        // Sampling frequency (Hz)
const float dt = 1.0 / fs;

// ==== Prediction handling ====
float v0_release = 0.0;
float t_pred_apex = 0.0;
float t_pred_absolute = 0.0;
bool apexPredScheduled = false;
bool apexPredSounded = false;

// ==== Sound parameters ====
const int freq_pred = 1200;  // predicted apex tone (high)
const int freq_real = 800;   // measured apex tone (low)

// ==== Filters ====
const float fc_acc = 50.0;
float alpha_acc;
float acc_filt_prev = 0;

const float fc_vel = 5.0;
float alpha_vel;
float velo_filt_prev = 0;
float velo_prev = 0;

// ==== Apex detection ====
float last_apex_time = -1000.0;
const float min_velocity = 0.02;  // m/s
const float min_dt = 0.3;         // seconds between apices

float velocity = 0;
float velocity_filt = 0;

// ==== Buzzer ====
const float filter_delay = 0.12; // seconds
bool buzzerActive = false;
unsigned long buzzerStartTime = 0;
const unsigned long buzzerDuration = 500; // milliseconds
bool buzzerStarted = false;

// ==== Free-fall detection ====
bool inFreeFall = false;
bool inFreeFallPrev = false;
float freeFallStartTime = 0.0;
const float FREEFALL_DELAY_COMP = 0.060; // seconds
const float LAND_IMPACT_THRESH = 1.3 * g; // detect landing

// ==== Setup ====
void setup() {
  // Initialize Bluetooth
  delay(200);
  BLE.begin();
  BLE.setLocalName("XIAO_IMU");
  BLE.setAdvertisedService(imuService);
  imuService.addCharacteristic(imuDataChar);
  BLE.addService(imuService);
  BLE.advertise();

  pinMode(buzzerPin, OUTPUT);
  Wire.begin();

  imu.begin();

  configFreeFall();

  // Compute filter coefficients
  alpha_acc = dt / (dt + 1.0 / (2.0 * 3.14159 * fc_acc));
  alpha_vel = 1.0 / (1.0 + 1.0 / (2.0 * 3.14159 * fc_vel * dt));
}

// ==== Configure Free-Fall ====
int configFreeFall() {
  uint8_t error = 0;
  uint8_t dataToWrite = 0;

  dataToWrite |= LSM6DS3_ACC_GYRO_BW_XL_200Hz;
  dataToWrite |= LSM6DS3_ACC_GYRO_FS_XL_2g;
  dataToWrite |= LSM6DS3_ACC_GYRO_ODR_XL_416Hz;
  error += imu.writeRegister(LSM6DS3_ACC_GYRO_CTRL1_XL, dataToWrite);

  error += imu.writeRegister(LSM6DS3_ACC_GYRO_WAKE_UP_DUR, 0x00);
  error += imu.writeRegister(LSM6DS3_ACC_GYRO_FREE_FALL, 0x70); // threshold/duration
  error += imu.writeRegister(LSM6DS3_ACC_GYRO_TAP_CFG1, 0x81); // enable detection

  return error;
}

// ==== Loop ====
void loop() {
  BLE.poll();
  static unsigned long lastMicros = 0;
  unsigned long now = micros();

  if (now - lastMicros >= dt * 1e6) {
    lastMicros = now;
    float current_time = millis() / 1000.0;

    // --- Read accelerometer ---
    float accX = imu.readFloatAccelX() * g;
    float accY = imu.readFloatAccelY() * g;
    float accZ = imu.readFloatAccelZ() * g;
    float acc_norm = sqrt(accX * accX + accY * accY + accZ * accZ) - g;

    // --- Low-pass filter accel ---
    float acc_filt = alpha_acc * acc_norm + (1 - alpha_acc) * acc_filt_prev;
    

    // --- High-pass filter velocity ---
    velocity_filt = alpha_vel * (velo_filt_prev + acc_filt * dt);

    // --- Read free-fall flag from IMU ---
    uint8_t src;
    imu.readRegister(&src, LSM6DS3_ACC_GYRO_WAKE_UP_SRC);
    bool inFreeFall = src & 0x20; // bit 5

    // --- Free-fall detection and apex prediction ---
    if (inFreeFall && !inFreeFallPrev) {
      freeFallStartTime = current_time - FREEFALL_DELAY_COMP;

      // Capture velocity at release (upward positive)
      v0_release = velo_filt_prev + acc_norm*dt;
      if (v0_release < 0) v0_release = 0;

      // Predict apex time (no drag)
      t_pred_apex = v0_release / g;           // time until apex
      t_pred_absolute = current_time + t_pred_apex;
      apexPredScheduled = true;
      apexPredSounded = false;
    }

    // --- Predicted apex buzzer ---
    if (apexPredScheduled && !apexPredSounded) {
      if (current_time >= t_pred_absolute) {
        tone(buzzerPin, freq_pred, 150);
        apexPredSounded = true;
      }
    }

    // --- Apex detection (measured: velocity crosses + to -) ---
    if (inFreeFall) {
      if ((velo_filt_prev > 0) && (velocity_filt <= 0)) {
        float apex_time = current_time - dt / 2;
        float apex_since_freefall = apex_time - freeFallStartTime;

        if ((apex_time - last_apex_time > min_dt)) {
          last_apex_time = apex_time;

          // Send time with BLE
          char buf[32];
          snprintf(buf, sizeof(buf), "%.3f, %.3f, %.3f", v0_release, t_pred_apex, apex_since_freefall);
          imuDataChar.setValue(buf);

          // Play different tone for measured apex
          //tone(buzzerPin, freq_real, 200);
          buzzerStartTime = millis() + filter_delay*1000;
          buzzerActive = true;

          // Log difference between predicted and actual apex
          float error = apex_time - t_pred_absolute;
        }
      }
    }

    // --- Landing detection and reset for next throw ---
    if (!inFreeFall && inFreeFallPrev) {
      // Potential landing event
      if (acc_norm > LAND_IMPACT_THRESH) {

        // Reset all state variables
        apexPredScheduled = false;
        apexPredSounded   = false;
        last_apex_time    = -1000.0;
        buzzerActive      = false;
        buzzerStarted     = false;
        v0_release        = 0.0;
        t_pred_apex       = 0.0;
        t_pred_absolute   = 0.0;
      }
    }

    // Update previous values
    inFreeFallPrev = inFreeFall;
    velo_filt_prev = velocity_filt;
    

    // --- Buzzer control (for scheduled events, if used) ---
    if (buzzerActive) {
      unsigned long now_ms = millis();

      if (!buzzerStarted && now_ms >= buzzerStartTime) {
        tone(buzzerPin, 1000);
        buzzerStarted = true;
      }

      if (buzzerStarted && now_ms >= buzzerStartTime + buzzerDuration) {
        noTone(buzzerPin);
        buzzerActive = false;
        buzzerStarted = false;
      }
    }
  }
}

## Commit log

2025-09-17 Create FindingVelocity
    Code to find velocity from ACC data
2025-09-18 New Arduino scripts
    For buzzer testing, storing on ram and streaming through bluetooth
    [collect_IMU_data.ino, store_IMU_RAM.ino, stream_bluethoot.ino]
2025-09-18 rename directory and files
    [Data 0904.xlsx]
2025-09-21 Add flight detection for Seeed Sensor
    flight detection model for a tenis ball based on acceleration, speed and orientation. Free fall detection from seed sensor and basic low pass filter. Then AHRS model for orientation
2025-09-21 Add MadgwickAHRS header file for IMU algorithms
    edit to public quaternion values
2025-09-21 Implement LSM6DS3 driver for Arduino
    mute line 108, is not necessary for current implementation mbed imu
2025-09-21 Add LSM6DS3 driver implementation
    mute line 108 and 110 not necessary for current implementation
2025-09-22 buzzer pin change
2025-09-27 Update the detecting apex with combined velocity file
2025-09-28 Edit flight detection logic and pin configuration
    clean structure. adjustments for flight detection and pin configuration. Print for debugging
2025-10-05 fix calibration frecuency data and debugging
2025-10-11 Electrical circuit desing added
    [Electrical circuit.kicad_pcb, Electrical circuit.kicad_sch]
2025-10-12 Gifs + results added
    [Results sensor vs video.xlsx]
2025-10-13 Name change
    [SmartServeBall.kicad_pcb, SmartServeBall.kicad_sch]
2025-10-13 Pictures sensor
2025-10-13 Delete Prototype Sensor Case/sensor case_left.SLDPRT
    na
    [sensor case_left.SLDPRT]
2025-10-13 Delete Prototype Sensor Case/sensor case_right.SLDPRT
    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
    [sensor case_right.SLDPRT]
2025-10-13 Update README with project description
    Added description for the Prototype Sensor Case.
2025-10-13 Enhance README with project details and guidelines for use of CAD files
    Updated README.md to include detailed project information, contents, design notes, implementation overview, tools, and licensing for the CAD files use
2025-10-13 Fix quaternion rotation calculations for acceleration
    [Apex_AHRS.ino]
2025-10-16 include graphs
    [Results sensor vs video.xlsx]
